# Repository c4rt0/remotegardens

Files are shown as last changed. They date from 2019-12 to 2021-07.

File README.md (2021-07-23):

# remotegardens
Remote garden solution based on micro-controllers (remotegardens.com) 

Video presentation available @ https://youtu.be/zsOXc0uMRTM 

Many years ago I came up with an idea of completely automatic grow system for various types of plants. Inspired by "The Martian" played by Matt Damon I thought of creating sort of independent plant environment controlled by machines. These days traditional agriculture accounts for, on average, 70 percent of all water withdrawals globally... hydroponics and aeroponics can be organic and solves this problem! Hydroponic gardens can be located at any location, without requirements for large land plots. Appropriately adapted small living (or storage) space can benefit in fresh product on regular basis. If so we can teach our machines to recognise best environment in order to acheive best quality product (i.e based on weight) - we will quickly eliminate the need of standard energy and resources waste. There's a long way ahead of us - let's start here.

In first stage of my aproach I need to implement simple system, which controlls irrigation conditions, but also takes under account certain environment factors (temperature & humidity). Values of most important parameters should be stored online for future investigation and record analysis. Furthermore, certain remote control should be avail in order to influence critical circumstances.

In the future my aim is to implement photoresistors or other light sensing devices to monitor intensity and conditions of photosynthesis, also gas sensors and other sensing mechanisms to fully understand and record growing conditions. Moreover, software will allow user to differentiate between different plant species, with hardcoded initial values for NPK, temperature, humidity, pH and other ratios. Over time this idea will evolve, and new features will be implemented... Now, let's start saving our PLANET.

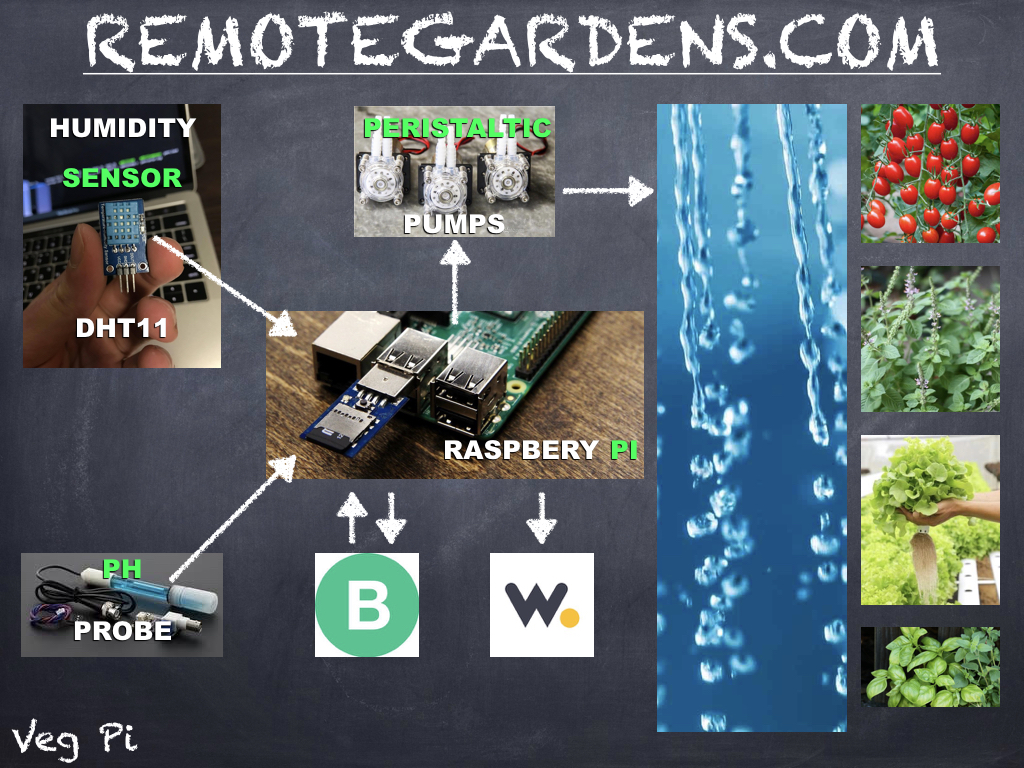
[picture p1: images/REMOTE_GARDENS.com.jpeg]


Using "Fritzing" app I started playing around with schematics. Firstly I connected my DHT11 sensor with Raspberry Pi. I noticed than, that PIN's layouts between different models of DHT11 sensors vary - in my case (from left) it's GND/DAT/VCC.
Few days later full schematics looked like this :

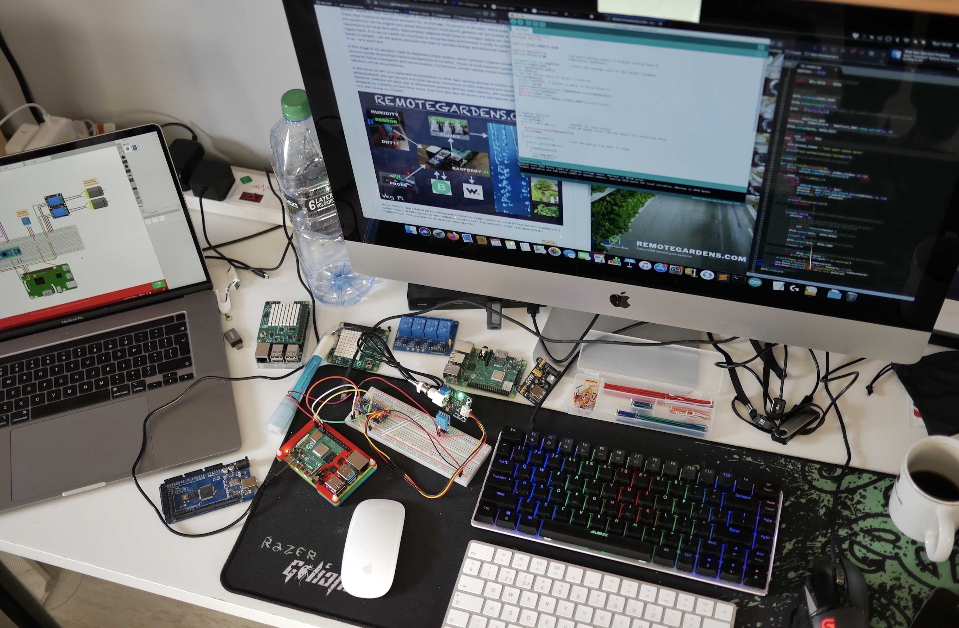
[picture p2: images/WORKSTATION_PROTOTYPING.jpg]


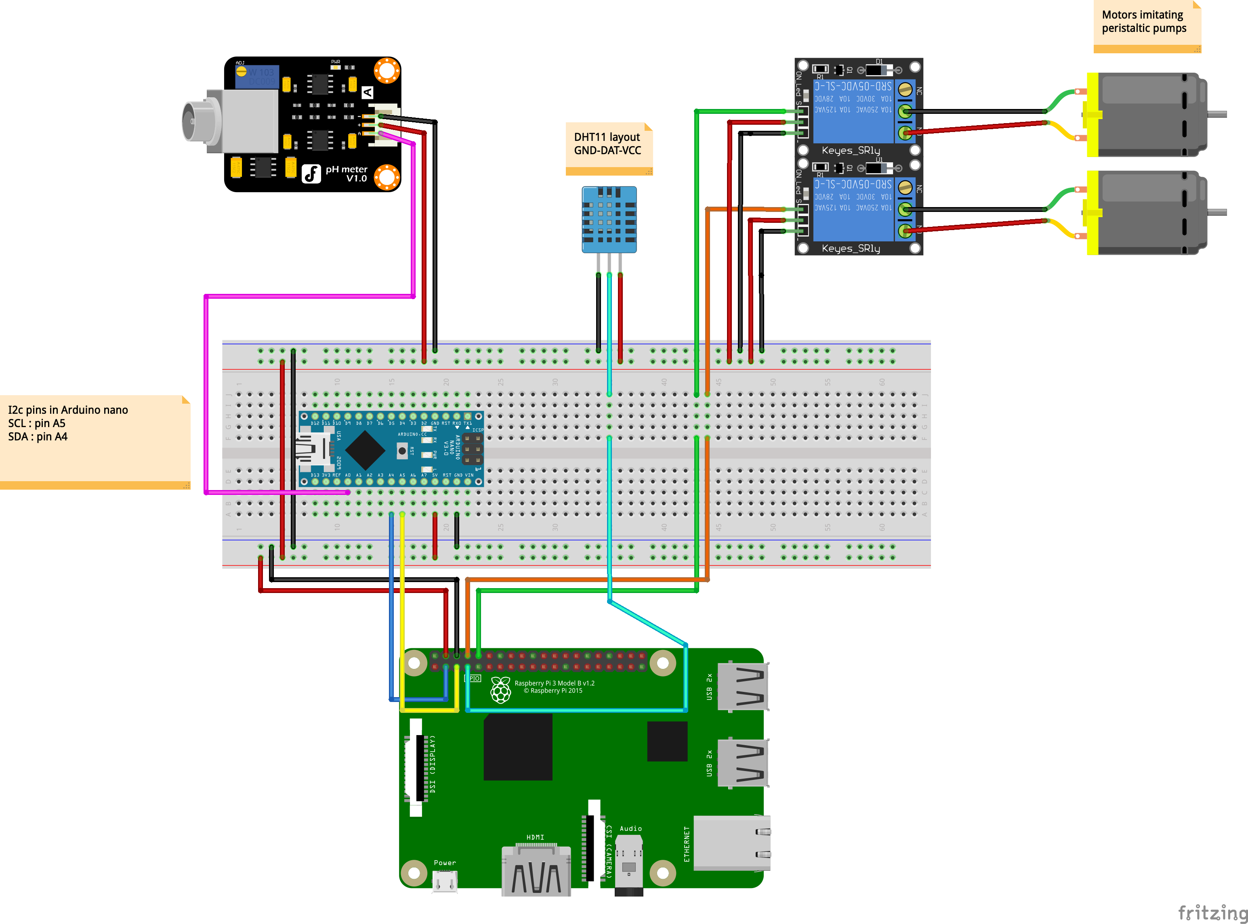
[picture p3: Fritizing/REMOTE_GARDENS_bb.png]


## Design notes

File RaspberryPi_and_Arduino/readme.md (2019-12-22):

Since pH probe and pH sensor play important role in my project I decided to present instructions on how I managed to connect both in a separate section.
Firstly I feel I need to clarify something that wasn't obvious to me at the very beginnings of this project: 

ph sensor outputs analog signal, while Raspberry Pi accepts only digital inputs.

This misterious sounding sentence became very clear really rapidly. I found out that instead of using analog-to-digital converter (ADC, A/D, or A-to-D)
I could simply use Arduino which I already had in my arsenal. 

Configuration of Arduino as a slave took a little bit of work - included in this folder is a i2c_slave file which was uploaded directly to Arduino through USB.

In order to check connectivity between Arduino and Pi after uploading i2c_slave we execute "sudo i2cdetect -y 1" command on Raspberry (result visible on the picture attached - bottom of terminal)

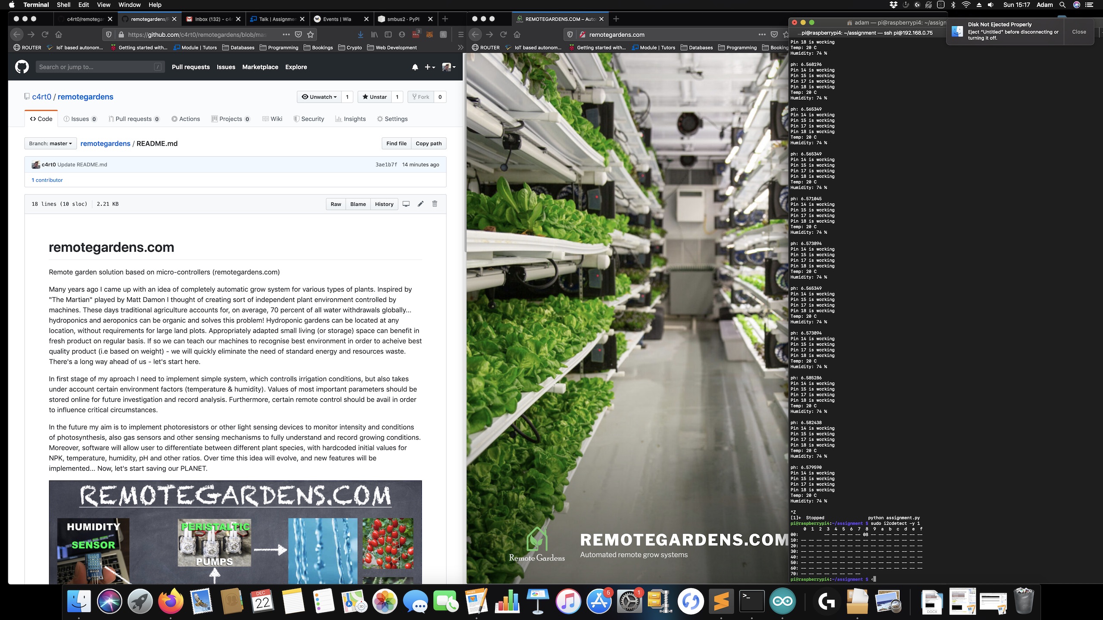
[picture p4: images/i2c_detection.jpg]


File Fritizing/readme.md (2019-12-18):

Files in this folder contain connection schematics created in Fritzing (*.fzz files) and corresponding *.jpg files.

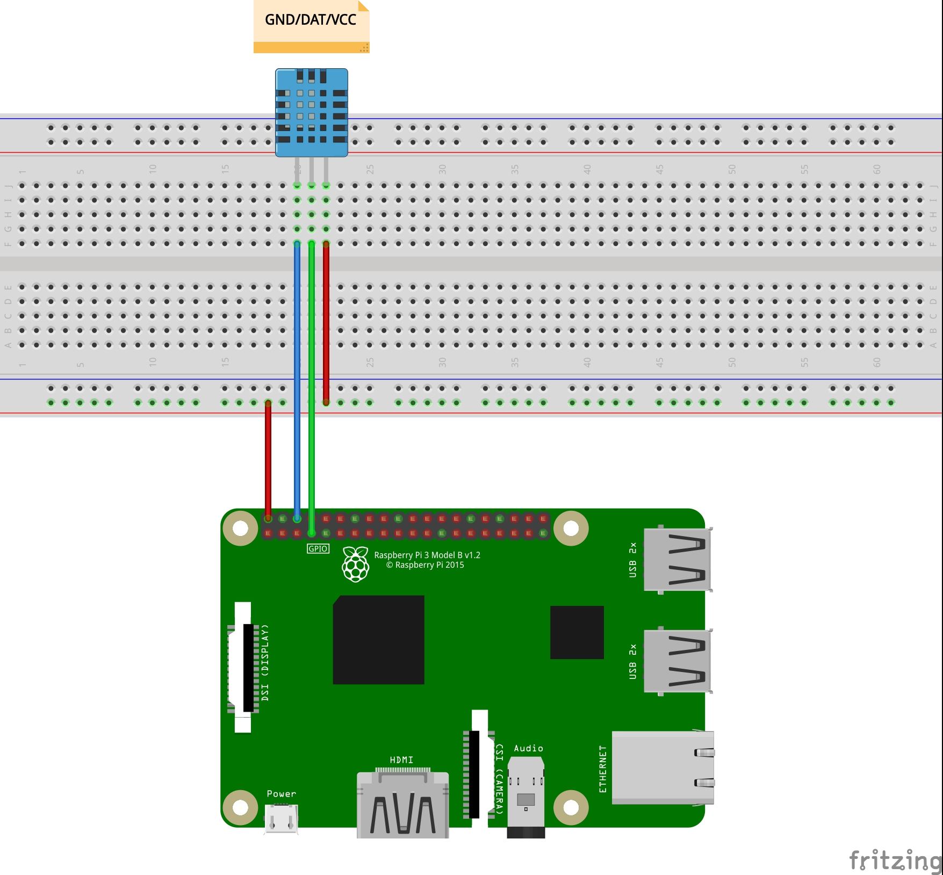
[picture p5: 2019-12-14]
Fritizing/Connecting_DHT11_bb.jpg

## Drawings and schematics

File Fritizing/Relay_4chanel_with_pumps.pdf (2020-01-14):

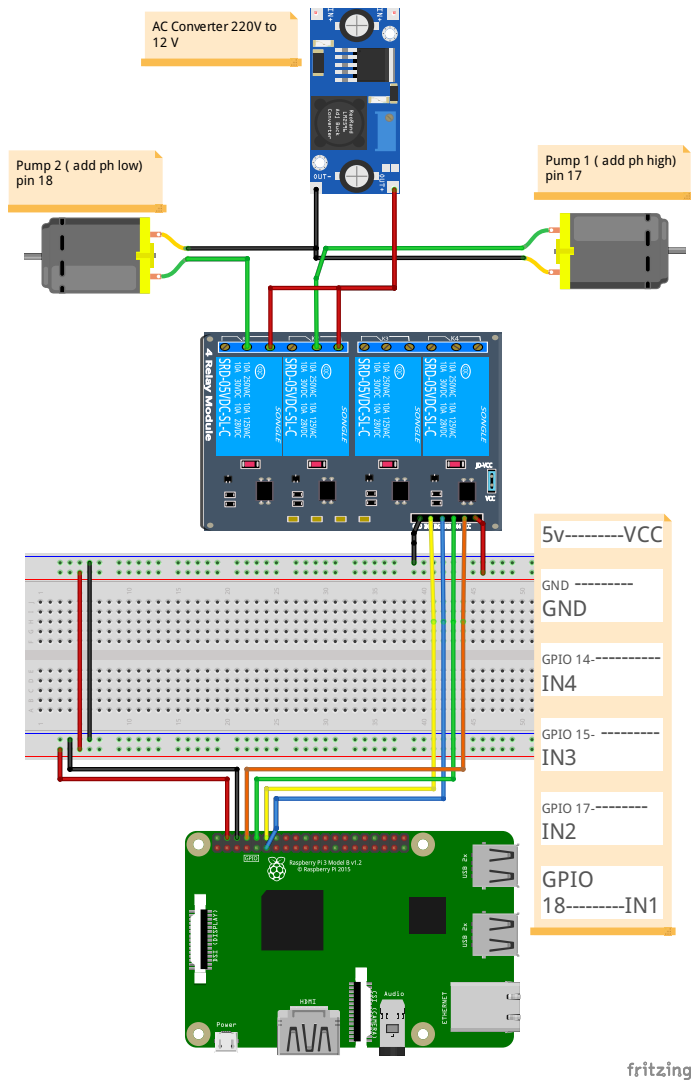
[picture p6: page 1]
5v---------VCC; GND --------- GND; GPIO 14----------- IN4; GPIO 15- --------- IN3; GPIO 17--------- IN2; GPIO 18---------IN1

AC Converter 220V to

Pump 2 ( add ph low)
pin 18

Pump 1 ( add ph high)
pin 17

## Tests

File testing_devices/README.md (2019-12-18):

This folder contains images and code in relation to devices considered in initial stage of project planning.
Code presented in this folder only checks if devices comunicate with microcontroller.

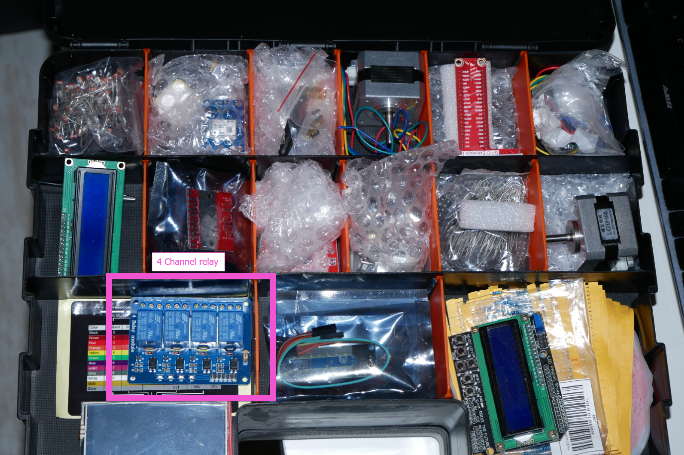
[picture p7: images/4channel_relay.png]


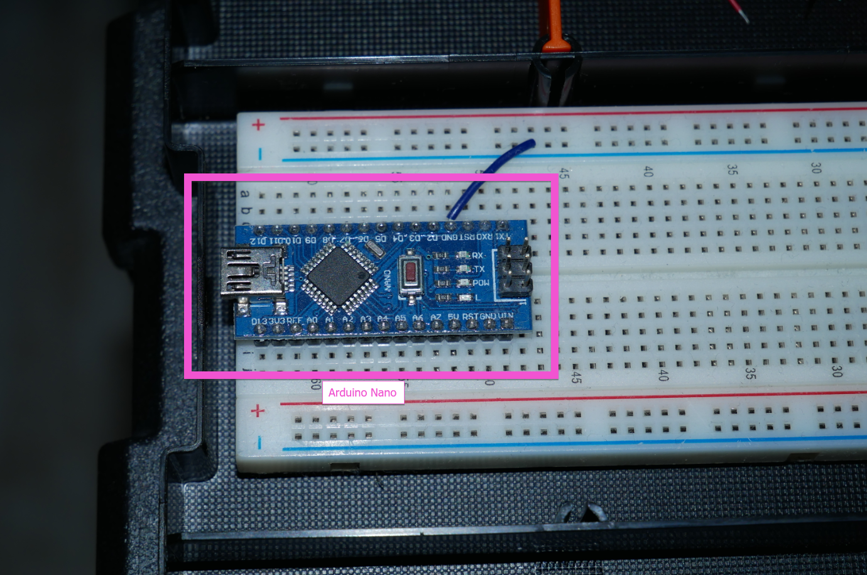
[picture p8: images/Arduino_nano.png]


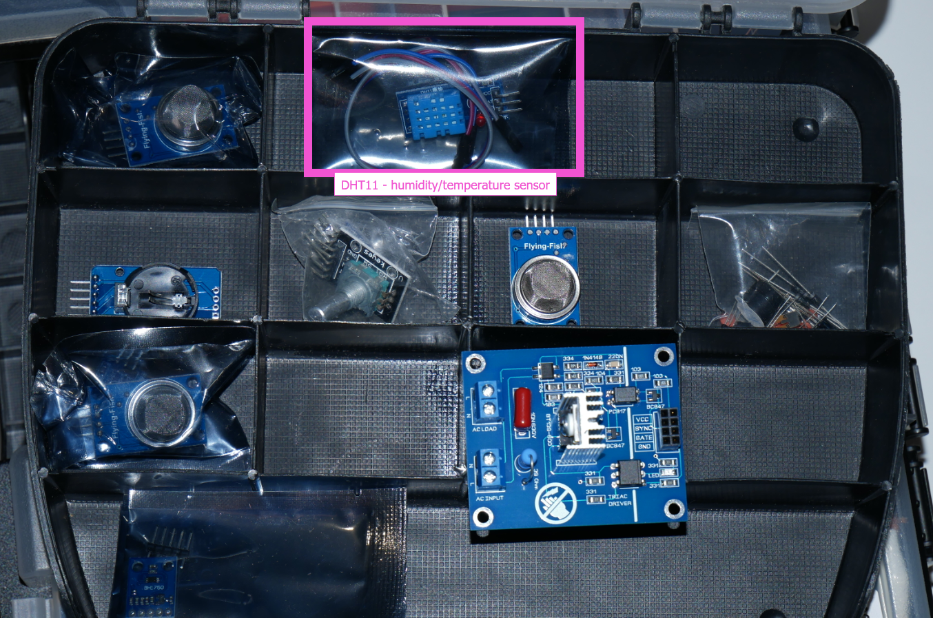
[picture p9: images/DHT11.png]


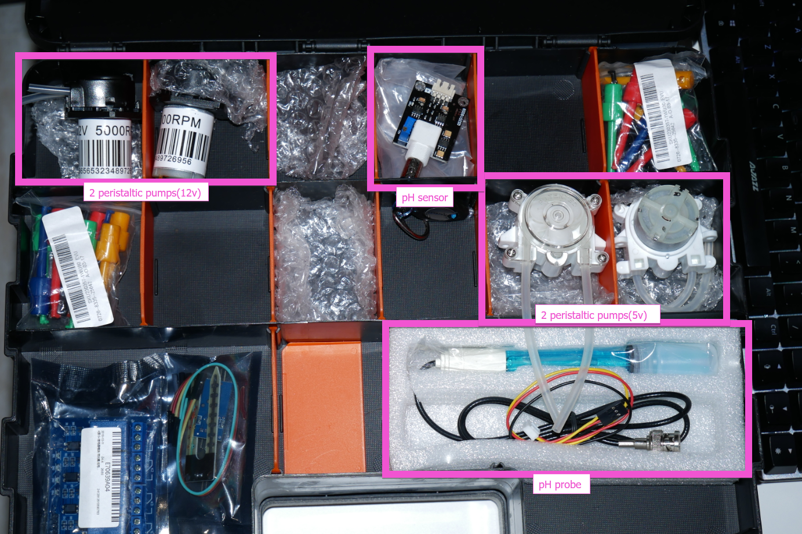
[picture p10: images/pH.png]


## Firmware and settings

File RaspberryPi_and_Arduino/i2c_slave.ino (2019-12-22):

#include <Wire.h>
 
#define SLAVE_ADDRESS 0x08

#define SensorPin 0            //pH meter Analog output to Arduino Analog Input 0
#define Offset 0.00            //deviation compensate

unsigned long int avgValue;     //Store the average value of the sensor feedback
#define FLOATS_SENT 1 
float data[FLOATS_SENT];
float phValue;
// Use the offset value to select a function
void sendData(){
  uint8_t buf[32]; // buffer in which to build block.*/
  uint8_t len=0;
  memmove(&buf[len],(uint8_t*)&phValue,sizeof(phValue));
  len += sizeof(phValue); 
  Wire.write(buf,len);
  Wire.write((byte*) &data, FLOATS_SENT*sizeof(float));
 
}

// Counter function
int PhSensor() {
   int buf[10];                //buffer for read analog
  for(int i=0;i<10;i++)       //Get 10 sample value from the sensor for smooth the value
  {
    buf[i]=analogRead(SensorPin);
    delay(100);
  }
  for(int i=0;i<9;i++)        //sort the analog from small to large
  {
    for(int j=i+1;j<10;j++)
    {
      if(buf[i]>buf[j])
      {
        int temp=buf[i];
        buf[i]=buf[j];
        buf[j]=temp;
      }
    }
  }
  avgValue=0;
  for(int i=2;i<8;i++)                      //take the average value of 6 center sample
    avgValue+=buf[i];
  phValue=(float)avgValue*5.0/1024/6;       //convert the analog into millivolt
  phValue=3.5*phValue+Offset;               //convert the millivolt into pH value
  Serial.print("    pH:"); 
  Serial.print(phValue,2);
  Serial.println(" ");
  return phValue;

  
 
}
 
 
void setup(){
 
  Serial.begin(9600); // start serial for output
  Wire.begin(SLAVE_ADDRESS);
  Wire.onRequest(sendData);
  Serial.println("I2C Ready!");
}
 
 
void loop(){

 data[0] = PhSensor(); 
 delay(500);
}

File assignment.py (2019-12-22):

#!/usr/bin/env python
from time import sleep

# i2c initialisation 
from smbus2 import SMBusWrapper
import struct
address = 0x08 # address on Raspberry Pi bus received with : sudo i2cdetect -y 1
 
# getting the main GPIO library
import RPi.GPIO as GPIO 


#relay initialisation
# setting a current mode
GPIO.setmode(GPIO.BCM)
#removing the warings 
GPIO.setwarnings(False)
#creating a list (array) with the number of GPIO's that I use (only two out of four are active 
# since I only plan on connecting two peristaltic pumps)
pins = [15,14] 

#dht11 initialisation (11,4) 11 is a type of a DHT sensor, 4 is a pin to where it's connected
import Adafruit_DHT
humidity, temperature = Adafruit_DHT.read_retry(11, 4)
#setting the mode for all pins so all will be switched on 
GPIO.setup(pins, GPIO.OUT)

# wia init
from wia import Wia
wia = Wia()
try: 
  wia.access_token = "My_private_Wia_key"
except:
  print("wia authorization failed\n")

# Giving the I2C device time to settle
sleep(1)

def get_float(data,index):
    bytes = bytearray(data[4*index:(index+1)*4])
    return struct.unpack("f",bytes)[0]

if __name__ == '__main__':
	while 1:
	    try:
		with SMBusWrapper(1) as bus:
		    phvalue = bus.read_i2c_block_data(address, 0, 16)
		    phvalue = get_float(phvalue,0)	   
		    print("ph: %f " % phvalue)
		    
	    except:
		print("**error**\n**")
	        continue
	    
	    # Decreasing delay may create more transmission errors.
	    sleep(0.0005)
	    if phvalue > 4:
		    for pin in reversed(pins) :
			#setting the GPIO to HIGH or 1 or true
			GPIO.output(pin,  GPIO.HIGH)
			#wait 0,5 second
			sleep(0.5)
			#setting the GPIO to LOW or 0 or false
			GPIO.output(pin,  GPIO.LOW)
			#wait 0,5 second
			sleep(0.5)

			#Checking if the current relay is running and printing it 
			if not GPIO.input(pin) : 
				print("Pin "+str(pin)+" is working")

	    print("Temp: %d C" % temperature)
            print("Humidity: %d %%" % humidity +"\n")
	    wia.Event.publish(name="temperature", data=temperature)
	    wia.Event.publish(name="ph", data=phvalue)
#cleaning all GPIO's 
GPIO.cleanup()

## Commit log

2019-12-18 Add files via upload
    Devices considered during initial stage of project planning.
2019-12-19 Add files via upload
    Complete_schematics
    [REMOTE_GARDENS.fzz]
2019-12-22 Add files via upload
    I2c slave file uploaded through USB directly to Arduino nano.
2019-12-22 Add files via upload
    detecting location of a slave (Arduino) with a commend :
    sudo i2cdetect -y 1
2019-12-22 Add files via upload
    Remote gardens code file responsible for control of Raspberry Pi. Reads pH Value from Arduino, takes humidity and temperature from DHT11 sensor - also controls 4-channel relay where peristaltic pumps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
2020-01-14 Add files via upload
    Here I managed to figure out how to connect it all to additional/external power supply.
2020-01-14 Add files via upload
    Fritzing *.fzz file explaining connectivity of pumps to external Power Supply.
    [Relay_4chanel_with_pumps.fzz]
